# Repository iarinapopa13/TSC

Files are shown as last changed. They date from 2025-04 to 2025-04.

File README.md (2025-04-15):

# TSC
### Iarina-Ioana Popa, 332CA

# OpenBook eBook Reader – Hardware Overview
Acest proiect de eBook Reader utilizeaza microcontrollerul *ESP32-C6*, fiind proiectat pentru consum redus de energie, conectivitate avansata si adaptabilitate hardware.

## Diagrama Block
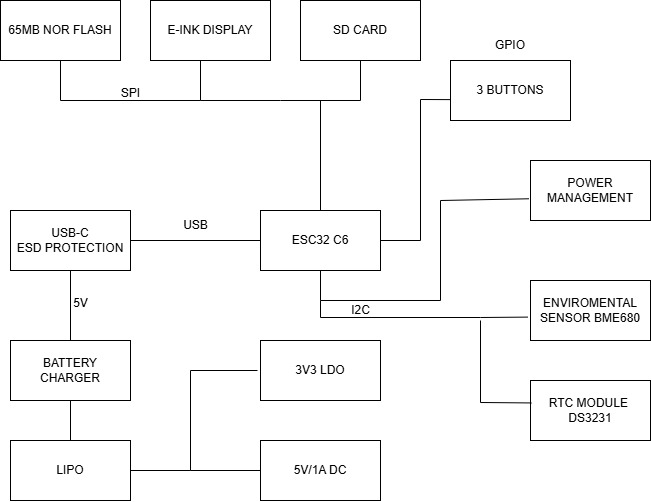
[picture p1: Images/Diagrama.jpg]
Diagrama Block


## Microcontroller – ESP32-C6
- *Arhitectura:* RISC-V 32-bit
- *Conectivitate:* WiFi 6, Bluetooth 5.0 LE
- *Interfete disponibile:* SPI, I2C, UART, PWM, GPIO
- *Eficienta energetica:* moduri deep sleep implementate

## Display E-Paper
- *Conectivitate:* Header de 20 pini dedicat
- *Protocol:* SPI + GPIO
 - Semnale principale: EPD_CS, EPD_DC, EPD_RST, EPD_BUSY, etc.
- *Beneficii:* zero consum in stare inactiva, vizibilitate superioara la lumina naturala

## Ceas Timp Real – DS3231SN
- *Caracteristici:* Precizie ridicata (±2 ppm)
- *Protocol:* I2C (partajat pe SDA/SCL)
- *Alimentare secundara:* Supercapacitor

## Senzor Ambiental – BME688
- *Masuratori:* Temperatura, Umiditate, Presiune atmosferica, VOCs
- *Interfata:* I2C
 - SDA: IO1
 - SCL: IO2
- *Alimentare:* 3.3V
- *Adresa I2C:* 0x76

## Sistem de Alimentare
### MAX17048 – Monitor Baterie
- *Rol:* Masurare capacitate baterie LiPo
- *Protocol:* I2C (IO1, IO2)
### MCP73831 – Controller Incarcare
- *Functionalitate:* Incarcare baterie LiPo (USB la 3.7V)
- *Capacitate:* ~500 mA
- *Indicator:* LED status incarcare
### XC6204 – Regulator LDO
- *Tensiune intrare:* 5V (USB)
- *Tensiune iesire:* 3.3V
- *Capacitate curent:* 200 mA
- *Eficienta energetica:* < 1 µA in standby

## Memorie si Stocare
### Card microSD
- *Protocol:* SPI (IO4–IO9)
- *Utilizare:* Stocare eBooks, setari
### Memorie Flash – W25Q512JV (64MB)
- *Protocol:* SPI (pini dedicati: IO20–IO23)
- *Utilizare:* Stocare firmware, fonturi, resurse

## Supervisor Tensiune & Resetare
- *Component:* BD52xx
- *Rol:* Monitorizare tensiune si resetare sigura
- *Pin control:* IO0

## Extensie I2C – Qwiic / Stemma QT
- *Conector:* 4 pini (3V3, GND, SDA, SCL)
- *Protocol:* I2C (IO1, IO2)
- *Ecosistem:* Compatibil cu module Adafruit / SparkFun

## Profil Consum Energetic
| Componenta | Mod Activ | Mod Standby |
|---|---|---|
| ESP32-C6 | 80–150 mA | <10 µA |
| E-Paper | 20–30 mA | 0 µA |
| BME688 | 1.1 mA | 0.15 µA |
| RTC DS3231SN | 200 µA | 2 µA |
| SD Card | 20–100 mA | 0.2 µA |
| MAX17048 | 50 µA | 1 µA |
| NOR Flash | 20 mA | 5 µA |

## Mapare Pini – ESP32-C6
| Functionalitate | Pini GPIO |
|---|---|
| Card SD (SPI) | IO4, IO5, IO6, IO9 |
| Display E-Paper | IO10–IO19 |
| I2C (RTC, Senzor) | IO1 (SDA), IO2 (SCL) |
| Flash SPI extern | IO20–IO23 |
| Buton Reset / Boot | IO0 |

## BOM (Bill Of Materials)
| Componenta | Link Cumpărare | Datasheet |
|---|---|---|
| Condensatoare Tantalum | [Buy](https://ro.mouser.com/ProductDetail/KYOCERA-AVX/TAJW107M010RNJ?qs=Wtp%252Bf%2FAeVqIH8v1VxV%252B1Rg%3D%3D) | [Datasheet](https://ro.mouser.com/datasheet/2/40/TAJ-3165264.pdf) |
| Rezistente R0402 | [Buy](https://store.comet.srl.ro/Search/?keywords=r0402#eyJpcHAiOiIyMCIsIm0iOiIiLCJrIjoicjA0MDIifQ%3D%3D) | [Datasheet](https://www.yageo.com/upload/media/product/products/datasheet/rchip/PYu-RC_Group_51_RoHS_L_12.pdf) |
| Condensatoare C0402 | [Buy](https://store.comet.srl.ro/CatalogueFarnell/Search/?keywords=c0402#eyJpcHAiOiIyMCIsImsiOiJjMDQwMiJ9) | [Datasheet](https://componentsearchengine.com/Datasheets/2/CC0402MRX5R5BB106.pdf) |
| 112A-TAAR-R03 | [Buy](https://store.comet.srl.ro/Catalogue/Product/43497/) | [Datasheet](https://www.snapeda.com/parts/112A-TAAR-R03/Attend/datasheet/) |
| SD0805S020S1R0 | [Buy](https://ro.mouser.com/ProductDetail/KYOCERA-AVX/SD0805S020S1R0?qs=jCA%252BPfw4LHbpkAoSnwrdjw%3D%3D) | [Datasheet](https://ro.mouser.com/datasheet/2/40/schottky-3165252.pdf) |
| MBR0530 | [Buy](https://ro.mouser.com/ProductDetail/onsemi-Fairchild/MBR0530?qs=VOMQJJE%252BBNniwJKcE3T43Q==) | [Datasheet](https://ro.mouser.com/datasheet/2/308/MBR0530_D-1810985.pdf) |
| CHG_LED | [Buy](https://ro.mouser.com/ProductDetail/Kingbright/KP-1608SURCK?qs=2JU0tDl2GZ3FuyEWfBV1%2Fg==) | [Datasheet](https://www.snapeda.com/parts/KP-1608SURCK/Kingbright/datasheet/) |
| PGB1010603MR | [Buy](https://www.digikey.com/en/products/detail/littelfuse-inc/PGB1010603MR/715755) | [Datasheet](https://www.littelfuse.com/assetdocs/pulseguard-esd-suppressors-pgb1-datasheet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) |
| ESP32-C6-WROOM-1-N8 | [Buy](https://ro.mouser.com/ProductDetail/Espressif-Systems/ESP32-C6-WROOM-1-N8?qs=8Wlm6%252BaMh8ST02Gmwp74cw%3D%3D) | [Datasheet](https://ro.mouser.com/datasheet/2/891/Espressif_ESP32_C6_WROOM_1__Datasheet_V0_1_PRELIMI-3239987.pdf) |
| DS3231SN | [Buy](https://store.comet.srl.ro/Catalogue/Product/47690/) | [Datasheet](https://ro.mouser.com/datasheet/2/609/DS3231-3421123.pdf) |
| BME680 | [Buy](https://ro.mouser.com/ProductDetail/Bosch-Sensortec/BME688?qs=IS%252B4QmGtzzqQoVDscqwx3A%3D%3D) | [Datasheet](https://ro.mouser.com/datasheet/2/783/bst_bme688_fl000-2307034.pdf) |
| USBLC6-2SC6Y | [Buy](https://ro.mouser.com/ProductDetail/STMicroelectronics/USBLC6-2SC6Y?qs=gNDSiZmRJS%2FOgDexvXkdow%3D%3D) | [Datasheet](https://ro.mouser.com/datasheet/2/389/usblc6_2sc6y-1852505.pdf) 
| MAX17048 | [Buy](https://ro.mouser.com/ProductDetail/Analog-Devices-Maxim-Integrated/MAX17048G%2bT10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) | [Datasheet](https://ro.mouser.com/datasheet/2/609/MAX17048_MAX17049-3469099.pdf) |
| MCP73831 | [Buy](https://ro.mouser.com/ProductDetail/Microchip-Technology/MCP73831T-2ATI-OT?qs=yUQqVecv4qsZbioEUu%252B83g%3D%3D) | [Datasheet](https://ro.mouser.com/datasheet/2/268/MCP73831_Family_Data_Sheet_DS20001984H-3441711.pdf) |
| BD5229G-TR | [Buy](https://www.digikey.com/en/products/detail/rohm-semiconductor/BD5229G-TR/3663792) | [Datasheet](https://fscdn.rohm.com/en/products/databook/datasheet/ic/power/voltage_detector/bd52xxg-e.pdf) |
| W25Q512JVEIQ | [Buy](https://ro.mouser.com/ProductDetail/Winbond/W25Q512JVEIQ?qs=l7cgNqFNU1jw6svr3at6tA%3D%3D) | [Datasheet](https://ro.mouser.com/datasheet/2/949/Winbond_W25Q512JV_Datasheet-3240039.pdf) |
| XC6220A331MR-G | [Buy](https://ro.mouser.com/ProductDetail/Torex-Semiconductor/XC6220A331MR-G?qs=AsjdqWjXhJ8ZSWznL1J0gg%3D%3D) | [Datasheet](https://ro.mouser.com/datasheet/2/760/xc6220-3371556.pdf) |
| USB4110-GF-A | [Buy](https://ro.mouser.com/ProductDetail/GCT/USB4110-GF-A?qs=KUoIvG%2F9IlYiZvIXQjyJeA%3D%3D) | [Datasheet](https://ro.mouser.com/datasheet/2/837/GCT_USB4110_Product_Drawing___20k_cycles-3455479.pdf) |
| FH34SRJ | [Buy](https://ro.mouser.com/ProductDetail/Hirose-Connector/FH34SRJ-24S-0.5SH99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) | [Datasheet](https://ro.mouser.com/datasheet/2/185/FH34SRJ_24S_0_5SH_99__CL0580_1255_6_99_2DDrawing_0-1615044.pdf) |
| Si1308EDL-T1-GE3 | [Buy](https://www.digikey.com/en/products/detail/vishay-siliconix/SI1308EDL-T1-GE3/4876435) | [Datasheet](https://www.vishay.com/docs/63399/si1308edl.pdf) |
| PFMF.050.1 | [Buy](https://ro.mouser.com/ProductDetail/EPCOS-TDK/B72520T0350K062?qs=dEfas%2FXlABIszF52uu7vrg%3D%3D) | [Datasheet](https://www.tdk-electronics.tdk.com/inf/75/db/CTVS_14/Surge_protection_series.pdf) |
| DMG2305UX-7 | [Buy](https://www.digikey.com/en/products/detail/diodes-incorporated/DMG2305UX-7/4340666) | [Datasheet](https://www.diodes.com/assets/Datasheets/DMG2305UX.pdf) |
| SJ (Solder Jumpers) | [Buy](https://grabcad.com/library/solder-jumpers-1) | [Datasheet](https://grabcad.com/library/solder-jumpers-1) |
| Butoane | [Buy](https://industry.panasonic.com/global/en/products/control/switch/light-touch/number/evqpuj02k) | [Datasheet](https://industry.panasonic.com/global/en/downloads?tab=catalog&small_g_cd=203&part_no=EVQPUJ02K) |
| CPH3225A | [Buy](https://www.digikey.com/en/products/detail/seiko-instruments/CPH3225A/8692444) | [Datasheet](https://mm.digikey.com/Volume0/opasdata/d220001/medias/docus/6537/rev05-CPHCPM.pdf) |
| QWIIC_RIGHT_ANGLE | [Buy](https://ro.mouser.com/ProductDetail/SparkFun/PRT-14417?qs=wd5RIQLrsJhgdz%2FpmZ%2F3GQ==) | [Datasheet](https://ro.mouser.com/datasheet/2/813/Qwiic_Connector_Datasheet-1223982.pdf) |
| Bobine 744043680 | [Buy](https://ro.mouser.com/ProductDetail/Wurth-Elektronik/744043680?qs=PGXP4M47uW6VkZq%252BkzjrHA%3D%3D) | [Datasheet](https://www.we-online.com/components/products/datasheet/744043680.pdf) |

## Note aditionale
- Aproximativ 130 vias la PCB
- Placuta in format 3D prezinta o diferenta de cativa mm in zona de sud a acesteia
- TP-urile nu au putut fi plasate precum in schema initiala, pentru evitarea viasurilor acestea au fost plasate cat mai aproape fata de  componentele de care se legau in urma procesului de rutare
- Bobina a suferit modificari din cauza erorilor date de ERC
- U4 a suferit modificari la SMD hole
- Am deplasat putin la dreaota una dintre mufe pentru a alinia perfect USB-ul

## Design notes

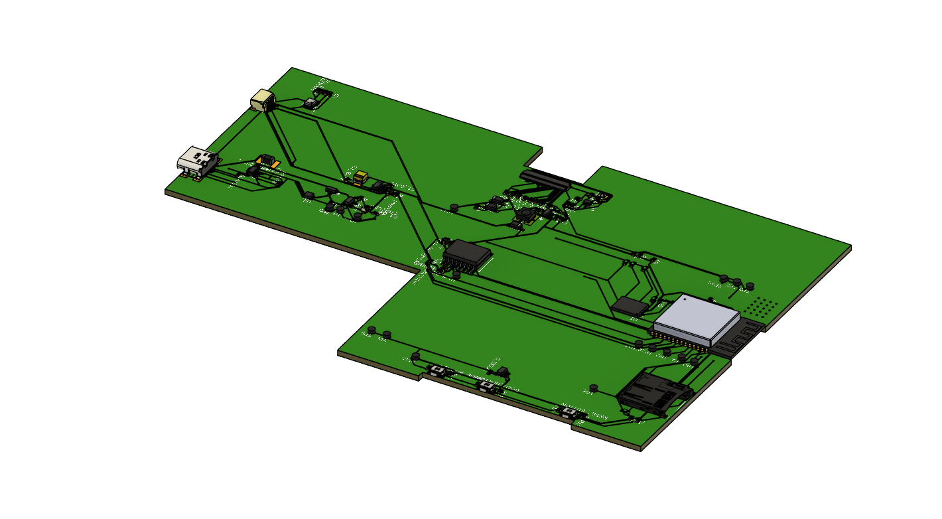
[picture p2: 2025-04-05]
Images/PCBfata2.png

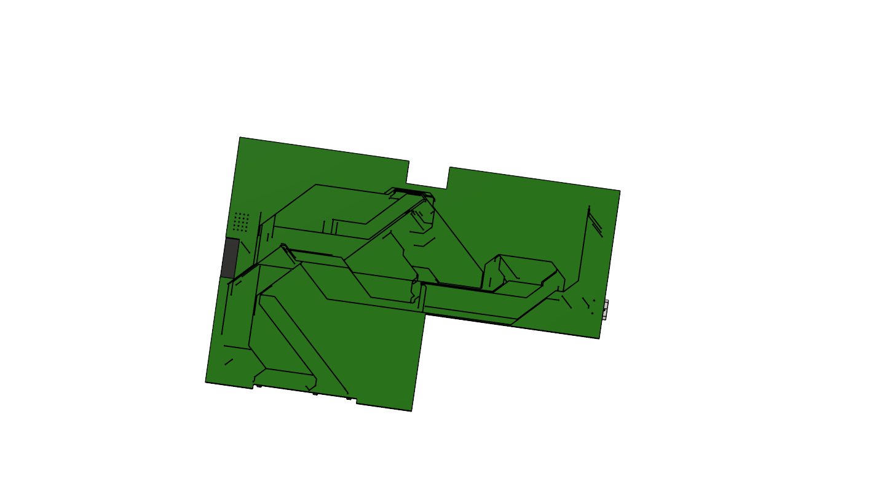
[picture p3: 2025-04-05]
Images/BackPCB.png

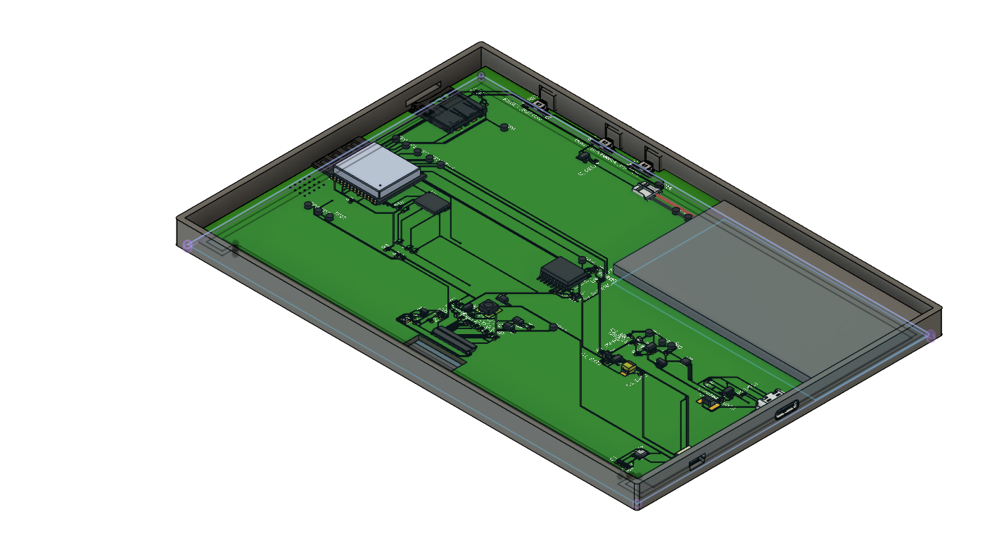
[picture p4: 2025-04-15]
Images/Placa_in_carcasa.png

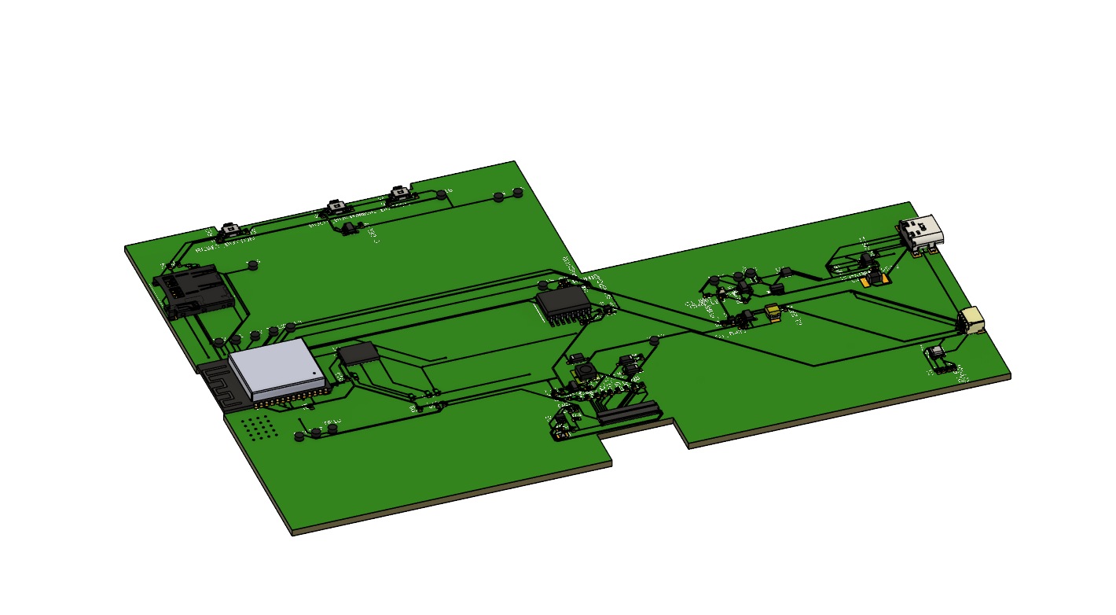
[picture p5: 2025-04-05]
Images/PCBfata1.png

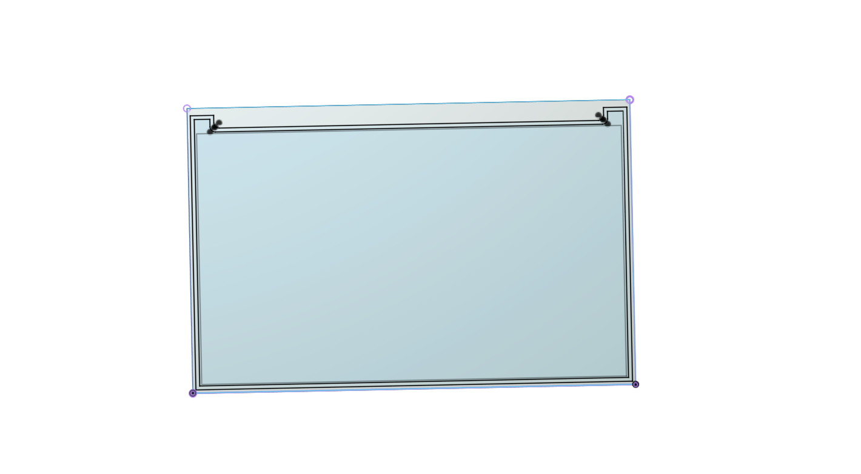
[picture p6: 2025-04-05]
Images/Display.png

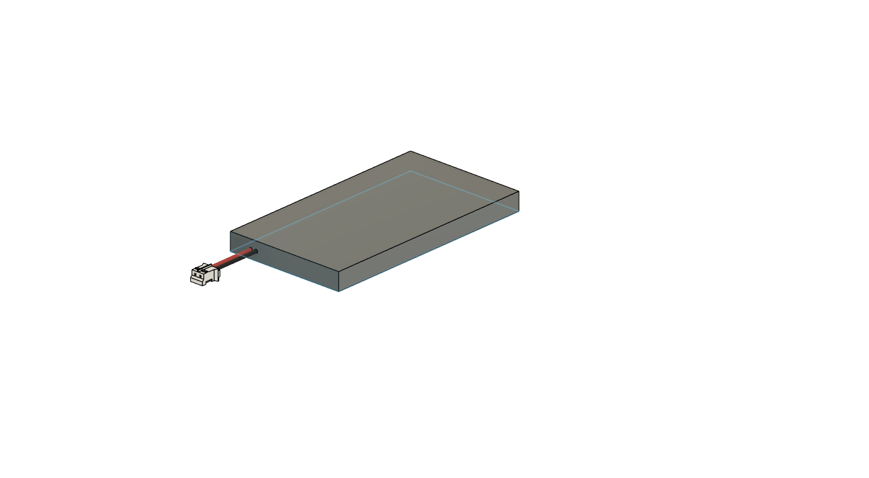
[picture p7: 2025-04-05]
Images/Baterie.png

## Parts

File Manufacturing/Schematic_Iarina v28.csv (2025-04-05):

Qty | Value | Device | Package | Parts | Description | 1 | 2 | ARROW_PART_NUMBER | ARROW_PRICE-STOCK | AVAILABILITY | CENTROID_NOT_SPECIFIED | CHECK_PRICES | COPYRIGHT | DATASHEET | DESCRIPTION | DIGIKEY_DESCRIPTION | DIGIKEY_PART_NUMBER | DMG2305UX-7 | HEIGHT | LEAD_FREE | MANUFACTURER_NAME | MANUFACTURER_PART_NUMBER | MF | MFR_NAME | MOUSER_PART_NUMBER | MOUSER_PRICE-STOCK | MOUSER_TESTING_PART_NUMBER | MOUSER_TESTING_PRICE-STOCK | MP | MPN | PACKAGE | POPULARITY | PREFIX | PRICE | PROD_ID | PURCHASE-URL | ROHS | SD0805S020S1R0 | SNAPEDA_LINK | SPICEMODEL | SPICEPREFIX | TEMPERATURE_RANGE_HIGH | TEMPERATURE_RANGE_LOW | TP_SIGNAL_NAME | VALUE
1 |  | ADAFRUIT_LEDCHIP-LED0603 | ADAFRUIT_CHIP-LED0603 | CHG_LED | LED
1 |  | SJ | SJ | SJ1 | SMD solder JUMPER |  |  |  |  |  |  |  |  |  |  |  |  |  |  |  |  |  |  |  |  |  |  |  |  |  |  | 3
1 | 0.47 | ESP32_WROVER_EAGLE-LTSPICE_RR0402 | ESP32_WROVER_EAGLE-LTSPICE_R0402 | R3 | RESISTOR, European symbol |  |  |  |  |  |  |  |  |  |  |  |  |  |  |  |  |  |  |  |  |  |  |  |  |  |  |  |  |  |  |  |  |  |  | NONE | R
1 | 100K | ESP32_WROVER_EAGLE-LTSPICE_RR0402 | ESP32_WROVER_EAGLE-LTSPICE_R0402 | R1_PWRUSB | RESISTOR, European symbol |  |  |  |  |  |  |  |  |  |  |  |  |  |  |  |  |  |  |  |  |  |  |  |  |  |  |  |  |  |  |  |  |  |  | NONE | R
8 | 100nF | EAGLE-LTSPICE_CC0402 | EAGLE-LTSPICE_C0402 | C1, C2, C4_USB, C6, C8, C9, C10, C_DELAY | CAPACITOR, European symbol |  |  |  |  |  |  |  |  |  |  |  |  |  |  |  |  |  |  |  |  |  |  |  |  |  |  |  |  |  |  |  |  |  |  | NONE | C
1 | 100uF TANT | RCL_CPOL-EUCT3528 | RCL_CT3528 | C3 | POLARIZED CAPACITOR, European symbol |  |  |  |  |  |  |  |  |  |  |  |  |  |  |  |  |  |  |  |  |  |  |  |  |  |  | 0 |  |  |  |  |  |  |  |  | C
14 | 10K | ESP32_WROVER_EAGLE-LTSPICE_RR0402 | ESP32_WROVER_EAGLE-LTSPICE_R0402 | R1, R1_PINH, R1_PINH1, R2-PINH, R2-PINH1, R4, R6, R7, R8, R9, R10, R_BOOT, R_CHANGE, R_RESET | RESISTOR, European symbol |  |  |  |  |  |  |  |  |  |  |  |  |  |  |  |  |  |  |  |  |  |  |  |  |  |  |  |  |  |  |  |  |  |  | NONE | R
1 | 10K\ | ESP32_WROVER_EAGLE-LTSPICE_RR0402 | ESP32_WROVER_EAGLE-LTSPICE_R0402 | R5 | RESISTOR, European symbol |  |  |  |  |  |  |  |  |  |  |  |  |  |  |  |  |  |  |  |  |  |  |  |  |  |  |  |  |  |  |  |  |  |  | NONE | R
1 | 10k | ESP32_WROVER_EAGLE-LTSPICE_RR0402 | ESP32_WROVER_EAGLE-LTSPICE_R0402 | R_CL1 | RESISTOR, European symbol |  |  |  |  |  |  |  |  |  |  |  |  |  |  |  |  |  |  |  |  |  |  |  |  |  |  |  |  |  |  |  |  |  |  | NONE | R
1 | 10uF | EAGLE-LTSPICE_CC0402 | EAGLE-LTSPICE_C0402 | C7 | CAPACITOR, European symbol |  |  |  |  |  |  |  |  |  |  |  |  |  |  |  |  |  |  |  |  |  |  |  |  |  |  |  |  |  |  |  |  |  |  | NONE | C
1 | 112A-TAAR-R03_ATTEND | 112A-TAAR-R03_ATTEND | 112ATAARR03ATTEND | J4 | Micro SD Card Socket, Push-Push Type, Top Mount, SMT, H=1.83mm, 10u |  |  |  |  |  |  |  |  |  | Micro SD Card Socket | Push-Push Type | Top Mount | SMT | H=1.83mm | 10u |  |  |  | 1.9mm |  | ATTEND | 112A-TAAR-R03 ATTEND
1 | 15 | ESP32_WROVER_EAGLE-LTSPICE_RR0402 | ESP32_WROVER_EAGLE-LTSPICE_R0402 | R_CAPACITOR | RESISTOR, European symbol |  |  |  |  |  |  |  |  |  |  |  |  |  |  |  |  |  |  |  |  |  |  |  |  |  |  |  |  |  |  |  |  |  |  | NONE | R
1 | 1uF | EAGLE-LTSPICE_CC0402 | EAGLE-LTSPICE_C0402 | C5 | CAPACITOR, European symbol |  |  |  |  |  |  |  |  |  |  |  |  |  |  |  |  |  |  |  |  |  |  |  |  |  |  |  |  |  |  |  |  |  |  | NONE | C
10 | 1uF/50V | EAGLE-LTSPICE_CC0402 | EAGLE-LTSPICE_C0402 | EPD_C1, EPD_C2, EPD_C5, EPD_C6, EPD_C7, EPD_C8, EPD_C9, EPD_C10, EPD_C11, EPD_C12 | CAPACITOR, European symbol |  |  |  |  |  |  |  |  |  |  |  |  |  |  |  |  |  |  |  |  |  |  |  |  |  |  |  |  |  |  |  |  |  |  | NONE | C
1 | 2.2 | ESP32_WROVER_EAGLE-LTSPICE_RR0402 | ESP32_WROVER_EAGLE-LTSPICE_R0402 | R2 | RESISTOR, European symbol |  |  |  |  |  |  |  |  |  |  |  |  |  |  |  |  |  |  |  |  |  |  |  |  |  |  |  |  |  |  |  |  |  |  | NONE | R
1 | 200 | ESP32_WROVER_EAGLE-LTSPICE_RR0402 | ESP32_WROVER_EAGLE-LTSPICE_R0402 | R1_BAT | RESISTOR, European symbol |  |  |  |  |  |  |  |  |  |  |  |  |  |  |  |  |  |  |  |  |  |  |  |  |  |  |  |  |  |  |  |  |  |  | NONE | R
2 | 20V/4.2A/52mO/1.4W | ESP32_WROVER_SPARKFUN-DISCRETESEMI_MOSFET_PCH-DMG2305UX-7 | ESP32_WROVER_SPARKFUN-DISCRETESEMI_SOT23-3 | Q1, Q2 | P-channel MOSFETs |  |  |  |  |  |  |  |  |  |  |  |  |  |  |  |  |  |  |  |  |  |  |  |  |  |  |  |  |  | TRAN-14388 |  |  |  |  |  |  |  |  |  | 20V/4.2A/52mO/1.4W
1 | 2K | ESP32_WROVER_EAGLE-LTSPICE_RR0402 | ESP32_WROVER_EAGLE-LTSPICE_R0402 | R2_BAT | RESISTOR, European symbol |  |  |  |  |  |  |  |  |  |  |  |  |  |  |  |  |  |  |  |  |  |  |  |  |  |  |  |  |  |  |  |  |  |  | NONE | R
5 | 4.7uF | EAGLE-LTSPICE_CC0402 | EAGLE-LTSPICE_C0402 | C1_BAT, C1_BAT1, C1_BAT2, C2_BAT, C5_USB | CAPACITOR, European symbol |  |  |  |  |  |  |  |  |  |  |  |  |  |  |  |  |  |  |  |  |  |  |  |  |  |  |  |  |  |  |  |  |  |  | NONE | C
1 | 4.7uF/25V | EAGLE-LTSPICE_CC0402 | EAGLE-LTSPICE_C0402 | C4 | CAPACITOR, European symbol |  |  |  |  |  |  |  |  |  |  |  |  |  |  |  |  |  |  |  |  |  |  |  |  |  |  |  |  |  |  |  |  |  |  | NONE | C
2 | 5k1 | ESP32_WROVER_EAGLE-LTSPICE_RR0402 | ESP32_WROVER_EAGLE-LTSPICE_R0402 | R2-USB, R2-USB1 | RESISTOR, European symbol |  |  |  |  |  |  |  |  |  |  |  |  |  |  |  |  |  |  |  |  |  |  |  |  |  |  |  |  |  |  |  |  |  |  | NONE | R
1 | 68uH | 744043680IND_4828-WE-TPC_WRE | IND_4828-WE-TPC_WRE | L1 |  |  |  |  |  |  |  |  | Copyright (C) 2024 Ultra Librarian. All rights reserved. |  |  |  |  |  |  |  |  | 744043680 |  | Wurth Electronics
1 | BD5229G-TR | BD5229G-TR | SOT95P280X125-5N | IC1 | Voltage Detector with Adjustable Delay Time: CMOS processes are utilized to develop high precision, low current consumption CMOS reset ICs that allow arbitrary setting of the delay time. The extensive lineup includes both Nch Open Drain and CMOS output types in a wide range of detection voltages (from 2.3V to 6.0V, in 0.1V steps), enabling selection of the ideal solution based on customer requirements. In addition, the entire series is of course both lead-free and RoHS-compliant. |  |  |  |  |  |  |  |  |  | Voltage Detector with Adjustable Delay Time: CMOS processes are utilized to develop high precision | low current consumption CMOS reset ICs that allow arbitrary setting of the delay time. The extensive lineup includes both Nch Open Drain and CMOS output types in a wide range of detection voltages (from 2.3V to 6.0V | in 0.1V steps) | enabling selection of the ideal solution based on customer requirements. In addition | the entire series is of course both lead-free and RoHS-compliant. |  |  |  | 1.25mm |  | ROHM Semiconductor | BD5229G-TR |  |  | 755-BD5229G-TR | https://www.mouser.co.uk/ProductDetail/ROHM-Semiconductor/BD5229G-TR?qs=4kLU8WoGk0vvnhrrYwdszw%3D%3D
1 | BME688 | ESP32_WROVER_BME680_BME680 | ESP32_WROVER_BME680_PSON80P300X300X100-8N | SENSOR2 | Integrated Environmental Unit |  |  |  |  | Unavailable |  |  |  |  | Integrated Environmental Unit |  |  |  |  |  |  |  | Bosch Sensortec |  |  |  |  |  | BME680 |  | LGA-8 Bosch Tools |  |  | None
3 | BUTTON_CUSYOMV1 | BUTTON_CUSYOMV1 | MYBUTTON | BOOT_BUTTON, CHANGE_BUTTON, RESET_BUTTON
1 | CPH3225A | EAGLE-LTSPICE_CC0402 | EAGLE-LTSPICE_C0402 | C10_SUPERCAP | CAPACITOR, European symbol |  |  |  |  |  |  |  |  |  |  |  |  |  |  |  |  |  |  |  |  |  |  |  |  |  |  |  |  |  |  |  |  |  |  | NONE | C
1 | DS3231SN# | DS3231SN# | SOIC127P1032X265-16N | U3 | Real Time Clock Serial 16-Pin SOIC W T/R Check availability |  |  |  |  | In Stock |  | https://www.snapeda.com/parts/DS3231SN%23/Analog+Devices/view-part/?ref=eda |  |  | Extremely Accurate I²C-Integrated RTC/TCXO/Crystal |  |  |  |  |  |  |  | Analog Devices |  |  |  |  |  | DS3231SN# |  | SOIC-16 Maxim |  |  | None |  | https://www.snapeda.com/api/url_track_click_mouser/?unipart_id=99048&manufacturer=Analog Devices&part_name=DS3231SN#&search_term=None |  |  | https://www.snapeda.com/parts/DS3231SN%23/Analog+Devices/view-part/?ref=snap
1 | ESP32-C6-WROOM-1-N8 | ESP32-C6-WROOM-1-N8 | XCVR_ESP32-C6-WROOM-1-N8 | U2 | Check availability |  |  |  |  | In Stock |  | https://www.snapeda.com/parts/ESP32-C6-WROOM-1-N8/Espressif+Systems/view-part/?ref=eda |  |  | Multiprotocol Modules ESP32-C6 module | Wi-Fi 6 in 2.4 GHz band | Bluetooth 5 | Zigbee 3.0 and Thread. ESP34-WROOM Compatible - ENGINEERING SAMPLE |  |  |  |  |  |  |  | Espressif Systems |  |  |  |  |  | ESP32-C6-WROOM-1-N8 |  | None |  |  | None |  |  |  |  | https://www.snapeda.com/parts/ESP32-C6-WROOM-1-N8/Espressif+Systems/view-part/?ref=snap
1 | ESP32C6_VARISTORCN1812 | ESP32C6_VARISTORCN1812 | ESP32C6_VARISTOR_CT/CN1812 | PFMF.050.1 | VARISTOR |  |  |  |  |  |  |  |  |  |  |  |  |  |  |  |  |  |  |  |  |  |  |  |  |  |  | 0
2 | ESP32_WROVER_AVX---SD0805S020S1R0_AVX_SD0805S020S1R0_0_0AVX_SD0805S020S1R0_0_0 | ESP32_WROVER_AVX---SD0805S020S1R0_AVX_SD0805S020S1R0_0_0AVX_SD0805S020S1R0_0_0 | ESP32_WROVER_AVX---SD0805S020S1R0_AVX_SD0805S020S1R0_0 | D2, D7 | Schottky Barrier Rectifier Diode |  |  |  |  |  | No |  |  | http://datasheets.avx.com/schottky.pdf |  | DIODE SCHOTTKY 20V 1A 0805 | 478-7800-1-ND |  |  | yes |  |  | AVX |  | 581-SD0805S020S1R0 |  |  |  |  |  | 0805 (2012 metric) |  | D |  |  |  | yes |  |  |  |  | +125°C | -55°C
1 | ESP32_WROVER_SPARKFUN-IC-POWER_MCP73831 | ESP32_WROVER_SPARKFUN-IC-POWER_MCP73831 | ESP32_WROVER_SPARKFUN-IC-POWER_SOT23-5 | MCP73831 | MCP73831T Li-Ion, Li-Pol Controller |  |  |  |  |  |  |  |  |  |  |  |  |  |  |  |  |  |  |  |  |  |  |  |  |  |  |  |  |  | IC-09995
1 | FH34SRJ-24S-0.5SH_99_ | FH34SRJ-24S-0.5SH_99_ | FH34SRJ24S05SH99 | J1 | (0.50mm) Surface Mount, Right Angle |  |  |  |  |  |  |  |  |  | 24 Position FFC | FPC Connector Contacts | (0.50mm) Surface Mount | Right Angle |  |  |  | 1.1mm |  | Hirose | FH34SRJ-24S-0.5SH(99) |  |  | 798-FH34SRJ24S05SH99 | https://www.mouser.co.uk/ProductDetail/Hirose-Connector/FH34SRJ-24S-0.5SH99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
1 | MAX17048G+T10 | MAX17048G+T10 | SON50P200X200X80-9N | U4 | Check availability |  |  |  |  | In Stock |  | https://www.snapeda.com/parts/MAX17048G+T10/Analog+Devices/view-part/?ref=eda |  |  | 3µA 1-Cell/2-Cell Fuel Gauge with ModelGauge |  |  |  |  |  |  |  | Analog Devices |  |  |  |  |  | MAX17048G+T10 |  | TDFN-8 Maxim |  |  | None |  | https://www.snapeda.com/api/url_track_click_mouser/?unipart_id=329239&manufacturer=Analog Devices&part_name=MAX17048G+T10&search_term=None |  |  | https://www.snapeda.com/parts/MAX17048G+T10/Analog+Devices/view-part/?ref=snap
3 | MBR0530 | MBR0530 | SOD3716X135N | D3, D4, D5 | ON SEMICONDUCTOR - MBR0530 - DIODE, SCHOTTKY, 0.5A, 30V, SOD-123 |  |  |  |  | In Stock |  | https://www.snapeda.com/parts/MBR0530/Onsemi/view-part/?ref=eda |  |  | Diode Schottky 30 V 500mA Surface Mount SOD-123 |  |  |  |  |  |  |  | ON Semiconductor |  |  |  |  |  | MBR0530 |  | SOD-123-2 ON Semiconductor |  |  | None |  | https://www.snapeda.com/api/url_track_click_mouser/?unipart_id=179458&manufacturer=ON Semiconductor&part_name=MBR0530&search_term=None |  |  | https://www.snapeda.com/parts/MBR0530/Onsemi/view-part/?ref=snap
6 | PGB1010603MR | PGB1010603MR | DIOC1608X36N | D6, D8, D9, D10, D11, D12 | Check availability |  |  |  |  | In Stock |  | https://www.snapeda.com/parts/PGB1010603MR/Littelfuse/view-part/?ref=eda |  |  | 150V (Typ) Clamp - Ipp Tvs Diode Surface Mount 0603 (1608 Metric) |  |  |  |  |  |  |  | Littelfuse Inc. |  |  |  |  |  | PGB1010603MR |  | 0603 Littelfuse Inc. |  |  | None |  | https://www.snapeda.com/api/url_track_click_mouser/?unipart_id=5659453&manufacturer=Littelfuse Inc.&part_name=PGB1010603MR&search_term=None |  |  | https://www.snapeda.com/parts/PGB1010603MR/Littelfuse/view-part/?ref=snap
1 | QWIIC_RIGHT_ANGLE | QWIIC_CONNECTORJS-1MM | JST04_1MM_RA | J3 | SparkFun I2C Standard Qwiic Connector |  |  |  |  |  |  |  |  |  |  |  |  |  |  |  |  |  |  |  |  |  |  |  |  |  |  |  |  |  | CONN-13694 |  |  |  |  |  |  |  |  |  | QWIIC_RIGHT_ANGLE
1 | SAMACSYS_PARTS_USB4110-GF-A | SAMACSYS_PARTS_USB4110-GF-A | SAMACSYS_PARTS_USB4110GFA | J2 | CONN USB 2.0 TYPE-C R/A SMT |  |  |  |  |  |  |  |  |  | CONN USB 2.0 TYPE-C R/A SMT |  |  |  | 3.26mm |  | GCT (GLOBAL CONNECTOR TECHNOLOGY) | USB4110-GF-A |  |  | 640-USB4110-GF-A | https://www.mouser.co.uk/ProductDetail/GCT/USB4110-GF-A?qs=KUoIvG%2F9IlYiZvIXQjyJeA%3D%3D
1 | SI1308EDL-T1-GE3 | SI1308EDL-T1-GE3 | SOT65P210X110-3N | Q3 | MOSFET N-Ch 30V 1.5A TrenchFET SC70 Vishay Si1308EDL-T1-GE3 N-channel MOSFET Transistor, 1.5 A, 30 V, 3-Pin SC-70 |  |  |  |  | In Stock |  | https://www.snapeda.com/parts/SI1308EDL-T1-GE3/Vishay+Siliconix/view-part/?ref=eda |  |  | Si1308EDL-T1-GE3 N-channel MOSFET Transistor | 1.5 A | 30 V | 3-Pin SC-70 | Siliconix / Vishay SI1308EDL-T1-GE3 |  |  |  |  |  |  |  | Vishay Siliconix |  |  |  |  |  | SI1308EDL-T1-GE3 |  | SOT-323 Vishay Semiconductor |  |  | None |  | https://www.snapeda.com/api/url_track_click_mouser/?unipart_id=274603&manufacturer=Vishay Siliconix&part_name=SI1308EDL-T1-GE3&search_term=None |  |  | https://www.snapeda.com/parts/SI1308EDL-T1-GE3/Vishay+Siliconix/view-part/?ref=snap
17 | TPTP20R | TPTP20R | TP20R | TP1, TP2, TP3, TP4, TP5, TP6, TP7, TP8, TP9, TP10, TP11, TP12, TP13, TP14, TP15, TP16, TP17 | Test pad |  |  |  |  |  |  |  |  |  |  |  |  |  |  |  |  |  |  |  |  |  |  |  |  |  |  | 2
1 | USBLC6-2SC6Y | USBLC6-2SC6Y | SOT95P280X145-6N | D1 | Low Cap. ESD Protection Auto SOT-23-6 STMicroelectronics USBLC6-2SC6Y, Dual Uni-Directional TVS Diode Array, 6-Pin SOT-23 |  |  |  |  | In Stock |  | https://www.snapeda.com/parts/USBLC6-2SC6Y/STMicroelectronics/view-part/?ref=eda |  |  | 17V Clamp 5A (8/20µs) Ipp Tvs Diode Surface Mount SOT-23-6 |  |  |  |  |  |  |  | STMicroelectronics |  |  |  |  |  | USBLC6-2SC6Y |  | SOT-23-6 STMicroelectronics |  |  | None |  |  |  |  | https://www.snapeda.com/parts/USBLC6-2SC6Y/STMicroelectronics/view-part/?ref=snap
1 | W25Q512JVEIQ | W25Q512JVEIQ | SON127P600X800X80-9N | U1 | Check availability |  |  |  |  | In Stock |  | https://www.snapeda.com/parts/W25Q512JVEIQ/Winbond+Electronics/view-part/?ref=eda |  |  | FLASH - NOR Memory IC 512Mb (64M x 8) SPI - Quad I/O 133 MHz 8-WSON (8x6) |  |  |  |  |  |  |  | Winbond Electronics |  |  |  |  |  | W25Q512JVEIQ |  | Package |  |  | None |  |  |  |  | https://www.snapeda.com/parts/W25Q512JVEIQ/Winbond+Electronics/view-part/?ref=snap
1 | XC6220A331MR-G | XC6220A331MR-G | SOT95P280X120-5N | IC4 | LDO Voltage Regulators |  |  |  |  |  |  |  |  |  | LDO Voltage Regulators |  |  |  | 1.2mm |  | Torex | XC6220A331MR-G |  |  | 865-XC6220A331MR-G | https://www.mouser.co.uk/ProductDetail/Torex-Semiconductor/XC6220A331MR-G?qs=AsjdqWjXhJ8ZSWznL1J0gg%3D%3D

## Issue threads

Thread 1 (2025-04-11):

[Schematic] Same value shown twice for the same component.

NoelaPirleci, 2025-04-11:
# Description
For the components: R1_BAT(Li-Po Battery Charging Controller) and R4(E-Paper Drive Circuit), you have the same value, shown twice.

# Solution
Remove one of the values for each component.

# Example

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

Closed 2025-04-15.

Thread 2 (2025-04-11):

[PCB] Fix GND pour.

NoelaPirleci, 2025-04-11:
# Description
There are places on the PCB that don't connect with GND.

# Solution
Add GND vias on those places. Be careful not to overlap with other routes when fixing.

# Example

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

Closed 2025-04-15.

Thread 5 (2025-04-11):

[README] Missing purchase links for the components.

NoelaPirleci, 2025-04-11:
# Description
The purchase links are missing for all the components in the BOM.

# Solution
Add the links for every component.
For example, here is the link for the capacitor: [https://www.digikey.com/en/products/detail/samsung-electro-mechanics/CL05B104KP5NNNC/3886660](https://www.digikey.com/en/products/detail/samsung-electro-mechanics/CL05B104KP5NNNC/3886660)

Closed 2025-04-15.

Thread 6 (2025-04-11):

[README] Bad link for coil model.

NoelaPirleci, 2025-04-11:
# Description
The link to the coil model redirects to a Micro SD Socket.

# Solution
Add the correct link.

Closed 2025-04-15.

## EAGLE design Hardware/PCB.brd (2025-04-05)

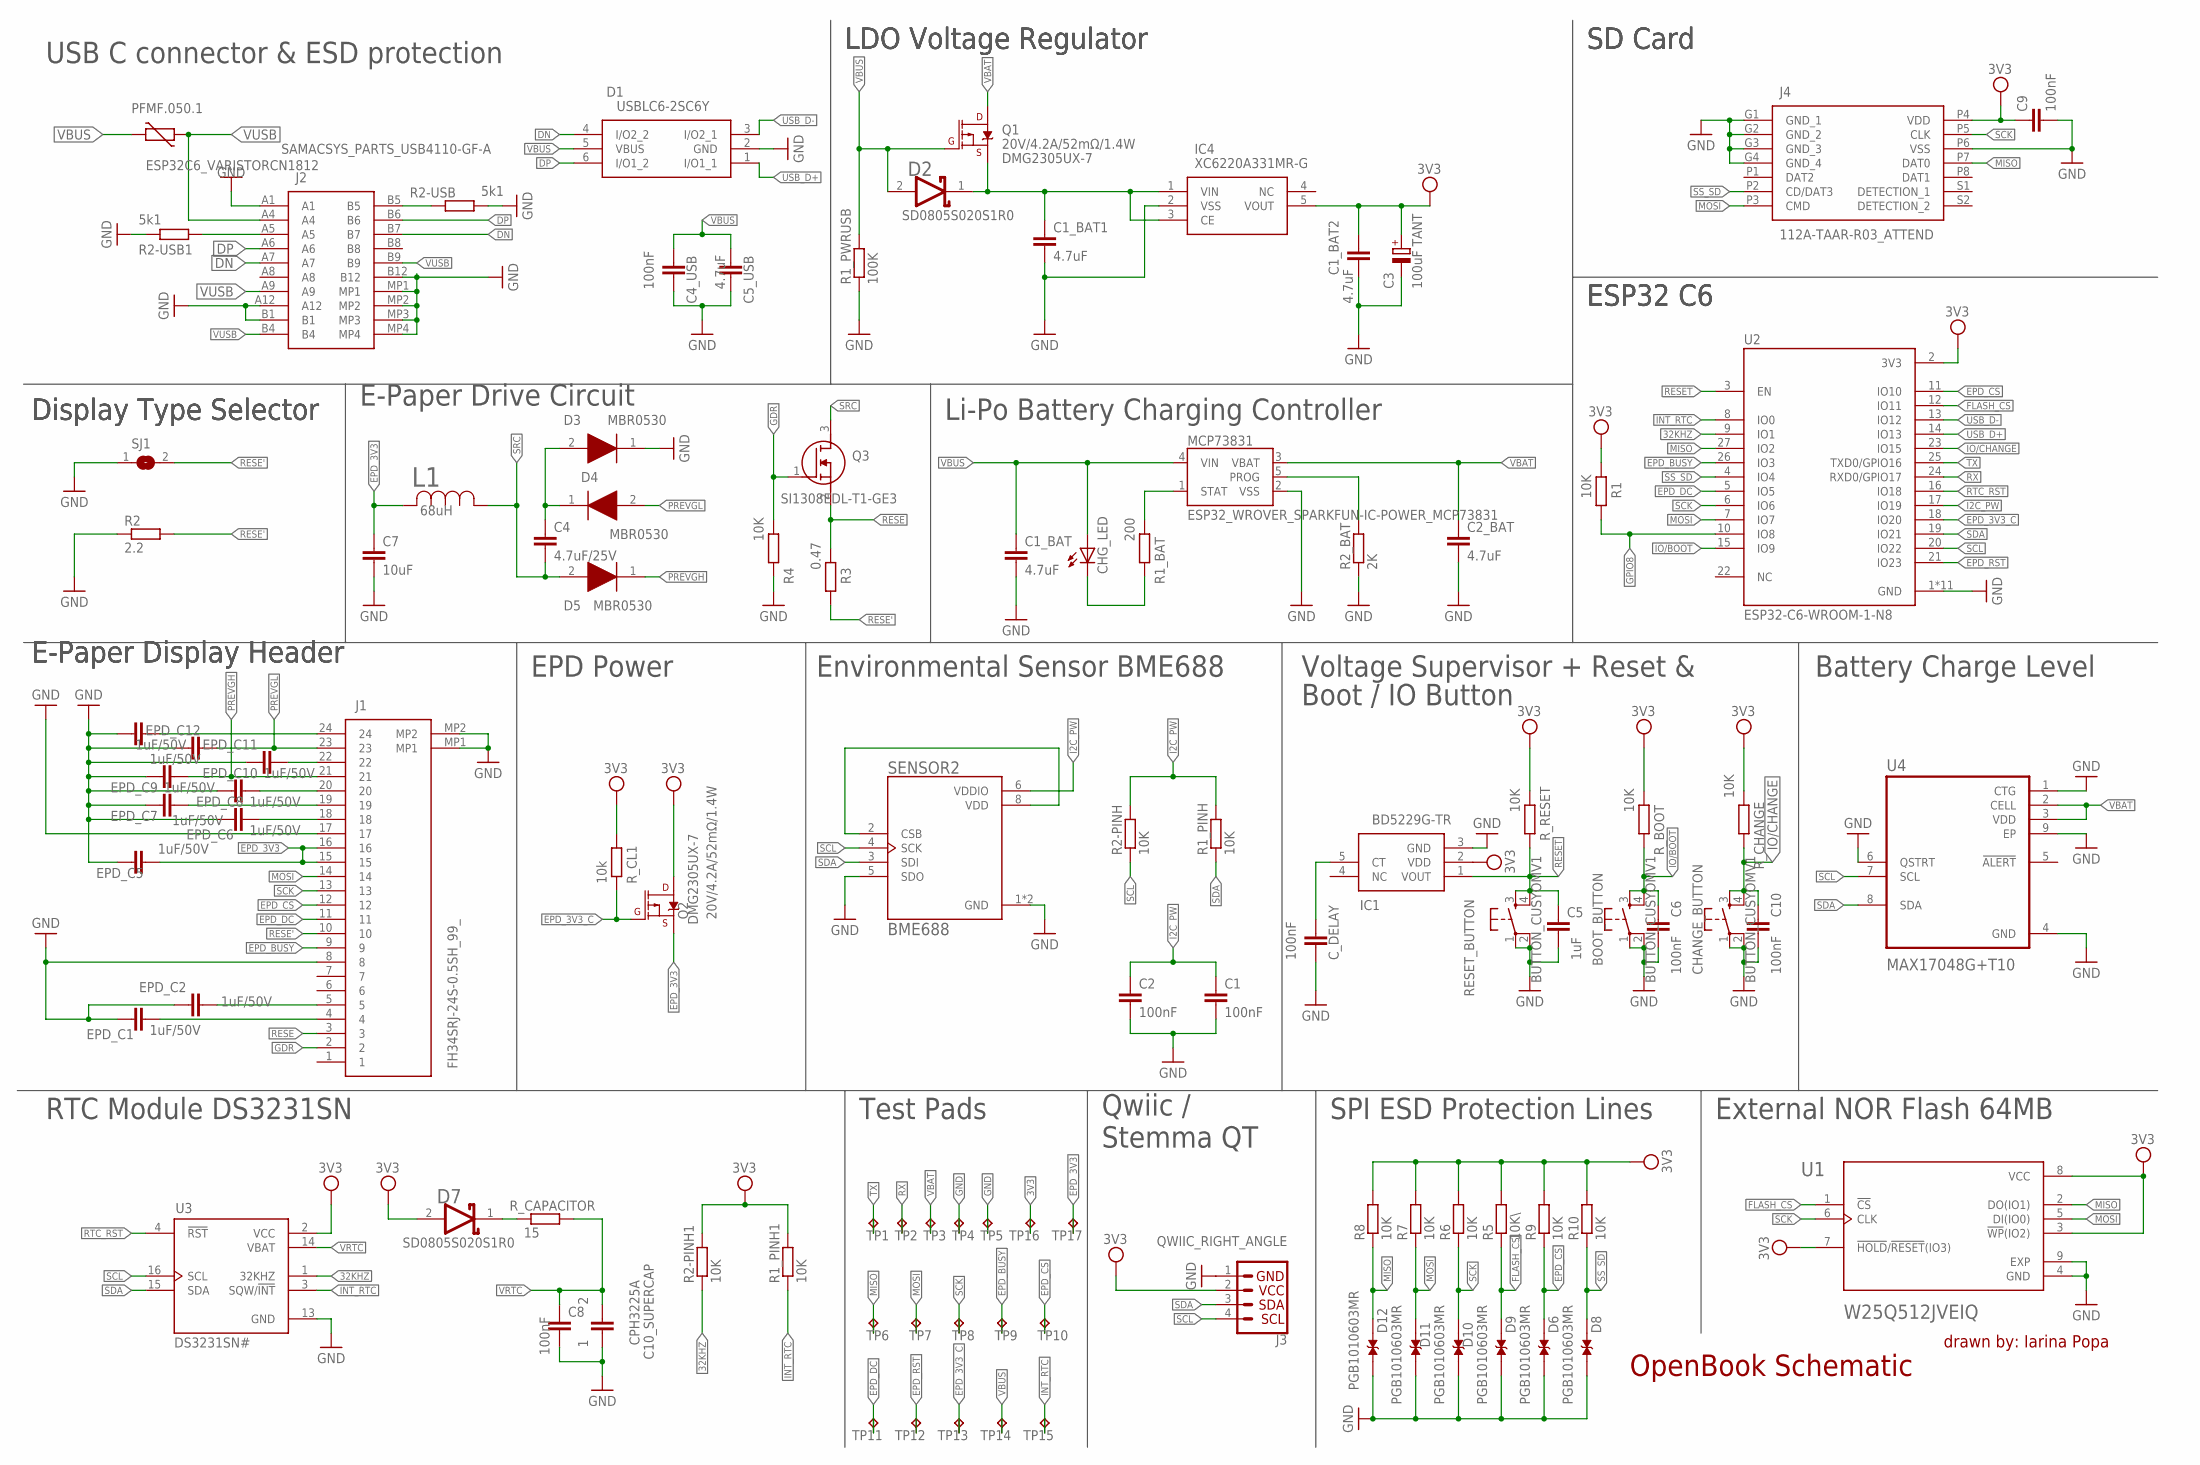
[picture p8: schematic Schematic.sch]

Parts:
BOOT_BUTTON: BUTTON_CUSYOMV1; MYBUTTON
C1, C2, C4_USB, C6, C8, C9, C10: 100nF; EAGLE-LTSPICE_C0402
C1_BAT, C1_BAT1, C1_BAT2, C2_BAT, C5_USB: 4.7uF; EAGLE-LTSPICE_C0402
C3: 100uF TANT; RCL_CT3528
C4: 4.7uF/25V; EAGLE-LTSPICE_C0402
C5: 1uF; EAGLE-LTSPICE_C0402
C7: 10uF; EAGLE-LTSPICE_C0402
C10_SUPERCAP: CPH3225A; EAGLE-LTSPICE_C0402
CHANGE_BUTTON: BUTTON_CUSYOMV1; MYBUTTON
CHG_LED: ADAFRUIT_LEDCHIP-LED0603; ADAFRUIT_CHIP-LED0603
C_DELAY: 100nF; EAGLE-LTSPICE_C0402
D1: USBLC6-2SC6Y; SOT95P280X145-6N
D2, D7: ESP32_WROVER_AVX---SD0805S020S1R0_AVX_SD0805S020S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; ESP32_WROVER_AVX---SD0805S020S1R0_AVX_SD0805S020S1R0_0
D3, D4, D5: MBR0530; SOD3716X135N
D6, D8, D9, D10, D11, D12: PGB1010603MR; DIOC1608X36N
EPD_C1, EPD_C2, EPD_C5, EPD_C6, EPD_C7, EPD_C8, EPD_C9, EPD_C10, EPD_C11, EPD_C12: 1uF/50V; EAGLE-LTSPICE_C0402
IC1: BD5229G-TR; SOT95P280X125-5N
IC4: XC6220A331MR-G; SOT95P280X120-5N
J1: FH34SRJ-24S-0.5SH_99_; FH34SRJ24S05SH99
J2: SAMACSYS_PARTS_USB4110-GF-A; SAMACSYS_PARTS_USB4110GFA
J3: QWIIC_RIGHT_ANGLE; JST04_1MM_RA
J4: 112A-TAAR-R03_ATTEND; 112ATAARR03ATTEND
L1: 68uH; IND_4828-WE-TPC_WRE
MCP73831: ESP32_WROVER_SPARKFUN-IC-POWER_MCP73831; ESP32_WROVER_SPARKFUN-IC-POWER_SOT23-5
PFMF.050.1: ESP32C6_VARISTORCN1812; ESP32C6_VARISTOR_CT/CN1812
Q1, Q2: 20V/4.2A/52mΩ/1.4W; ESP32_WROVER_SPARKFUN-DISCRETESEMI_SOT23-3
Q3: SI1308EDL-T1-GE3; SOT65P210X110-3N
R1, R1_PINH, R1_PINH1, R2-PINH, R2-PINH1, R4, R6, R7, R8, R9, R10: 10K; ESP32_WROVER_EAGLE-LTSPICE_R0402
R1_BAT: 200; ESP32_WROVER_EAGLE-LTSPICE_R0402
R1_PWRUSB: 100K; ESP32_WROVER_EAGLE-LTSPICE_R0402
R2: 2.2; ESP32_WROVER_EAGLE-LTSPICE_R0402
R2-USB, R2-USB1: 5k1; ESP32_WROVER_EAGLE-LTSPICE_R0402
R2_BAT: 2K; ESP32_WROVER_EAGLE-LTSPICE_R0402
R3: 0.47; ESP32_WROVER_EAGLE-LTSPICE_R0402
R5: 10K\; ESP32_WROVER_EAGLE-LTSPICE_R0402
RESET_BUTTON: BUTTON_CUSYOMV1; MYBUTTON
R_BOOT: 10K; ESP32_WROVER_EAGLE-LTSPICE_R0402
R_CAPACITOR: 15; ESP32_WROVER_EAGLE-LTSPICE_R0402
R_CHANGE: 10K; ESP32_WROVER_EAGLE-LTSPICE_R0402
R_CL1: 10k; ESP32_WROVER_EAGLE-LTSPICE_R0402
R_RESET: 10K; ESP32_WROVER_EAGLE-LTSPICE_R0402
SENSOR2: BME688; ESP32_WROVER_BME680_PSON80P300X300X100-8N
SJ1: SJ
TP1, TP2, TP3, TP4, TP5, TP6, TP7, TP8, TP9, TP10, TP11, TP12, TP13, TP14, TP15, TP16, TP17: TPTP20R; TP20R
U1: W25Q512JVEIQ; SON127P600X800X80-9N
U2: ESP32-C6-WROOM-1-N8; XCVR_ESP32-C6-WROOM-1-N8
U3: DS3231SN#; SOIC127P1032X265-16N
U4: MAX17048G+T10; SON50P200X200X80-9N

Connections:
3V3: C1_BAT2.1, C3.+, C9.1, D7.2 (ANODE), IC1.2 (VDD), IC4.5 (VOUT), J3.2, J4.P4 (VDD), Q2.3 (D), R1.2, R1_PINH1.2, R2-PINH1.2, R5.2, R6.2, R7.2, R8.2, R9.2, R10.2, R_BOOT.2, R_CHANGE.2, R_CL1.2, R_RESET.2, TP16.TP, U1.3 (!WP!(IO2)), U1.7 (!HOLD!/!RESET!(IO3)), U1.8 (VCC), U2.2 (3V3), U3.2 (VCC)
32KHZ: R2-PINH1.1, U2.9 (IO1), U3.1 (32KHZ)
DN: D1.4 (I/O2_2), J2.A7, J2.B7
DP: D1.6 (I/O1_2), J2.A6, J2.B6
EPD_3V3: C7.1, EPD_C5.2, J1.15, J1.16, L1.2, Q2.2 (S), TP17.TP
EPD_3V3_C: Q2.1 (G), R_CL1.1, TP13.TP, U2.18 (IO20)
EPD_BUSY: J1.9, TP9.TP, U2.26 (IO3)
EPD_CS: D6.2, J1.12, R9.1, TP10.TP, U2.11 (IO10)
EPD_DC: J1.11, TP11.TP, U2.5 (IO5)
EPD_RST: TP12.TP, U2.21 (IO23)
FLASH_CS: D9.2, R5.1, U1.1 (!CS), U2.12 (IO11)
GDR: J1.2, Q3.1 (G), R4.2
GND: BOOT_BUTTON.1, BOOT_BUTTON.2, C1.2, C1_BAT.2, C1_BAT1.2, C1_BAT2.2, C2.2, C2_BAT.2, C3.-, C4_USB.2, C5.2, C5_USB.2, C6.2, C7.2, C8.2, C9.2, C10.2, C10_SUPERCAP.2, CHANGE_BUTTON.1, CHANGE_BUTTON.2, C_DELAY.2, D1.2 (GND), D3.1 (K), D6.1, D8.1, D9.1, D10.1, D11.1, D12.1, EPD_C1.1, EPD_C2.1, EPD_C5.1, EPD_C6.1, EPD_C7.1, EPD_C8.1, EPD_C9.1, EPD_C10.1, EPD_C11.1, EPD_C12.1, IC1.3 (GND), IC4.2 (VSS), J1.8, J1.17, J1.MP1, J1.MP2, J2.A1, J2.A12, J2.B1, J2.B12, J2.MP1, J2.MP2, J2.MP3, J2.MP4, J3.1, J4.G1 (GND_1), J4.G2 (GND_2), J4.G3 (GND_3), J4.G4 (GND_4), J4.P6 (VSS), MCP73831.2 (VSS), R1_PWRUSB.1, R2.1, R2-USB.2, R2-USB1.1, R2_BAT.1, R4.1, RESET_BUTTON.1, RESET_BUTTON.2, SENSOR2.1 (GND), SENSOR2.5 (SDO), SENSOR2.7 (GND), SJ1.1, TP4.TP, TP5.TP, U1.4 (GND), U1.9 (EXP), U2.1 (GND), U2.28 (GND), U2.29_1 (GND), U2.29_2 (GND), U2.29_3 (GND), U2.29_4 (GND), U2.29_5 (GND), U2.29_6 (GND), U2.29_7 (GND), U2.29_8 (GND), U2.29_9 (GND), U3.13 (GND), U4.1 (CTG), U4.4 (GND), U4.6 (QSTRT), U4.9 (EP)
GPIO8: R1.1, U2.10 (IO8)
I2C_PW: C1.1, C2.1, R1_PINH.2, R2-PINH.2, SENSOR2.6 (VDDIO), U2.17 (IO19)
INT_RTC: R1_PINH1.1, TP15.TP, U2.8 (IO0), U3.3 (SQW/!INT)
IO/BOOT: BOOT_BUTTON.3, BOOT_BUTTON.4, C6.1, R_BOOT.1, U2.15 (IO9)
IO/CHANGE: C10.1, CHANGE_BUTTON.3, CHANGE_BUTTON.4, R_CHANGE.1, U2.23 (IO15)
MISO: D12.2, J4.P7 (DAT0), R8.1, TP6.TP, U1.2 (DO(IO1)), U2.27 (IO2)
MOSI: D11.2, J1.14, J4.P3 (CMD), R7.1, TP7.TP, U1.5 (DI(IO0)), U2.7 (IO7)
unnamed: J2.A5, R2-USB1.2
unnamed: J2.B5, R2-USB.1
unnamed: MCP73831.1 (STAT), R1_BAT.2
unnamed: CHG_LED.C, R1_BAT.1
unnamed: C1_BAT1.1, D2.1 (CATHODE), IC4.1 (VIN), IC4.3 (CE), Q1.2 (S)
unnamed: C4.1, D3.2 (A), D4.1 (K)
unnamed: MCP73831.5 (PROG), R2_BAT.2
unnamed: EPD_C1.2, J1.4
unnamed: EPD_C10.2, J1.22
unnamed: C_DELAY.1, IC1.5 (CT)
unnamed: EPD_C12.2, J1.24
unnamed: D7.1 (CATHODE), R_CAPACITOR.1
unnamed: EPD_C7.2, J1.19
unnamed: EPD_C8.2, J1.20
unnamed: EPD_C6.2, J1.18
unnamed: SENSOR2.2 (CSB), SENSOR2.8 (VDD)
unnamed: EPD_C2.2, J1.5
PREVGH: D5.1 (K), EPD_C9.2, J1.21
PREVGL: D4.2 (A), EPD_C11.2, J1.23
RESE: J1.3, Q3.2 (S), R3.2
RESE': J1.10, R2.2, R3.1, SJ1.2
RESET: C5.1, IC1.1 (VOUT), RESET_BUTTON.3, RESET_BUTTON.4, R_RESET.1, U2.3 (EN)
RTC_RST: U2.16 (IO18), U3.4 (!RST)
RX: TP2.TP, U2.24 (RXD0/GPIO17)
SCK: D10.2, J1.13, J4.P5 (CLK), R6.1, TP8.TP, U1.6 (CLK), U2.6 (IO6)
SCL: J3.4, R2-PINH.1, SENSOR2.4 (SCK), U2.20 (IO22), U3.16 (SCL), U4.7 (SCL)
SDA: J3.3, R1_PINH.1, SENSOR2.3 (SDI), U2.19 (IO21), U3.15 (SDA), U4.8 (SDA)
SRC: C4.2, D5.2 (A), L1.1, Q3.3 (D)
SS_SD: D8.2, J4.P2 (CD/DAT3), R10.1, U2.4 (IO4)
TX: TP1.TP, U2.25 (TXD0/GPIO16)
USB_D+: D1.1 (I/O1_1), U2.14 (IO13)
USB_D-: D1.3 (I/O2_1), U2.13 (IO12)
VBAT: C2_BAT.1, MCP73831.3 (VBAT), Q1.3 (D), TP3.TP, U4.2 (CELL), U4.3 (VDD)
VBUS: C1_BAT.1, C4_USB.1, C5_USB.1, CHG_LED.A, D1.5 (VBUS), D2.2 (ANODE), MCP73831.4 (VIN), PFMF.050.1.2, Q1.1 (G), R1_PWRUSB.2, TP14.TP
VRTC: C8.1, C10_SUPERCAP.1, R_CAPACITOR.2, U3.14 (VBAT)
VUSB: J2.A4, J2.A9, J2.B4, J2.B9, PFMF.050.1.1

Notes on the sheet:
USB C connector & ESD protection
LDO Voltage Regulator
SD Card
ESP32 C6
Li-Po Battery Charging Controller
E-Paper Drive Circuit
Display Type Selector
E-Paper Display Header
EPD Power
Environmental Sensor BME688
Boot / IO Button
Voltage Supervisor + Reset &
Battery Charge Level
RTC Module DS3231SN
Test Pads
Qwiic / Stemma QT
SPI ESD Protection Lines
External NOR Flash 64MB
OpenBook Schematic
drawn by: Iarina Popa

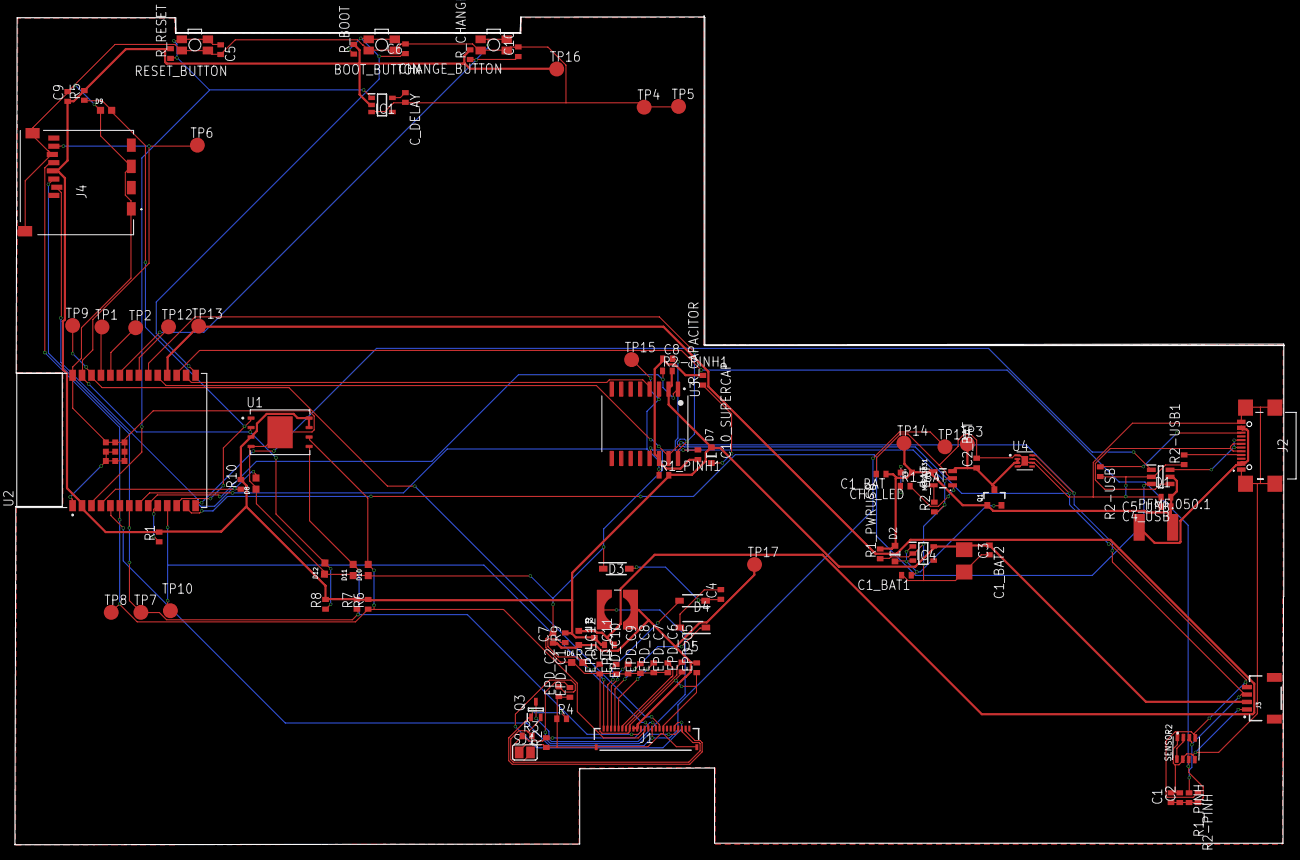
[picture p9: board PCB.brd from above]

Board: 2 copper layers, 170.3 x 111.1 mm, 103 parts (0 on the bottom side), 56 nets.

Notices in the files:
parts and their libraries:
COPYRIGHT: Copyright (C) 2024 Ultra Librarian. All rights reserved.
